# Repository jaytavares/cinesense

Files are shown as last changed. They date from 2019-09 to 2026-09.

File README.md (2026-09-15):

# Cinesense: an Audio Sensing Add-on for Bose Cinemate Speakers

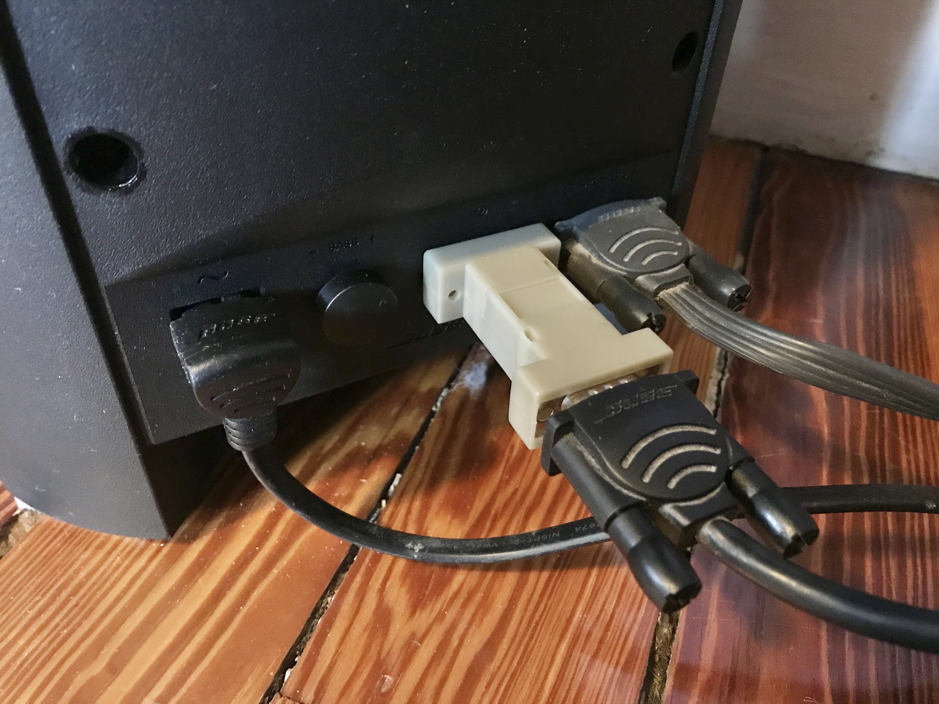
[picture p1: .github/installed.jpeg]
Assembled Board


## Overview

Do you have Bose Cinemate speakers? Do you wish they would just turn on automatically when you need them
and turn off when you're done. This project provides everything you need to do just that. Using it, you can create an
adapter that plugs into the interface module cable and adds audio sensing capability to your Bose Cinemate speakers.\*

\* This project only works with Bose Cinemate **Series II** speakers. Since the Cinemate Series I speakers don't have an optical audio input, the Cinesense will not work with them.

[Buy One!](#buy-one)

[Build It!](#the-parts-list)

## What People are Saying

> Amazing! Works perfectly. Didn’t expect it to auto shutoff after a couple of seconds when the source is powered off, so that’s a plus! Thanks again! _— Chris T._

> Just received it and installed it. What an awesome little gadget! Thanks for doing this for us and sending some joy our way. It may be a small thing. But pretty awesome! _— Jennifer S._

> Works like a charm! Thanks very much again. _— Miroslav V._

> Hey- just wanted to tell you the adapter works great! Thanks again! _— Graham L._

> Hey the adapter is installed and works great, thanks for making one for me, it's worth paying you for your ingenuity. I'm so much happier not having any remotes since I use google voice to do everything else other than volume changes. _— Enrique I._

> They work perfectly, thank you so much! _— David A._

> Received it today and it works as described. Thanks again! _— Jeremiah O._

> You’ve changed my life Jay!!!! Thank you!! _— Nathan R._

> The adapter works great! Thanks again Jay. _— Dmitrij P._

> Just got it in the mail, it's amazing!! Thank you so much! Timing was impeccable.. I literally was just looking at new speakers now I don't have to! You have no idea how happy this makes me haha _— Julie C._

> Dude, you’re a wizard! Love this thing. Who knew something so simple looking could be so helpful? Thanks again! _— Brian W._

### How It Works

When placed inline between the sub woofer module and the interface module, the Cinesense adapter repeatedly polls the
optical audio input for a signal. When a signal is sensed, the speakers are automatically turned on. The adapter will
continue to monitor the signal while the speakers are in use. Once the signal has stopped for ten seconds, the adapter
will turn the speakers off.

NOTE: The adapter only looks at the optical input and will not respond to audio signals on the analog inputs. This is a
potential future enhancement that can be made to the design. Also, the term "Audio Signal" here is referring to optical
audio "data" which is not the same as "sound". It's possible for the optical audio signal to be present _and_ silent
(e.g. music player is powered on but is paused).

Aside from the new found ability to automatically turn on and off in response to the audio signal, all aspects of the
speakers are the same. You can still use your remote to control the volume and mute the speakers. You can even use your
remote to turn the speakers off, though if there is an audio signal present, they'll just turn right back on again.

## Theory of Operation (for nerds)

Below I've included not just how the Cinesense works but everything I learned about these speakers in the course
of building this project. Hopefully it will be helpful to someone else interested in hacking these speakers.

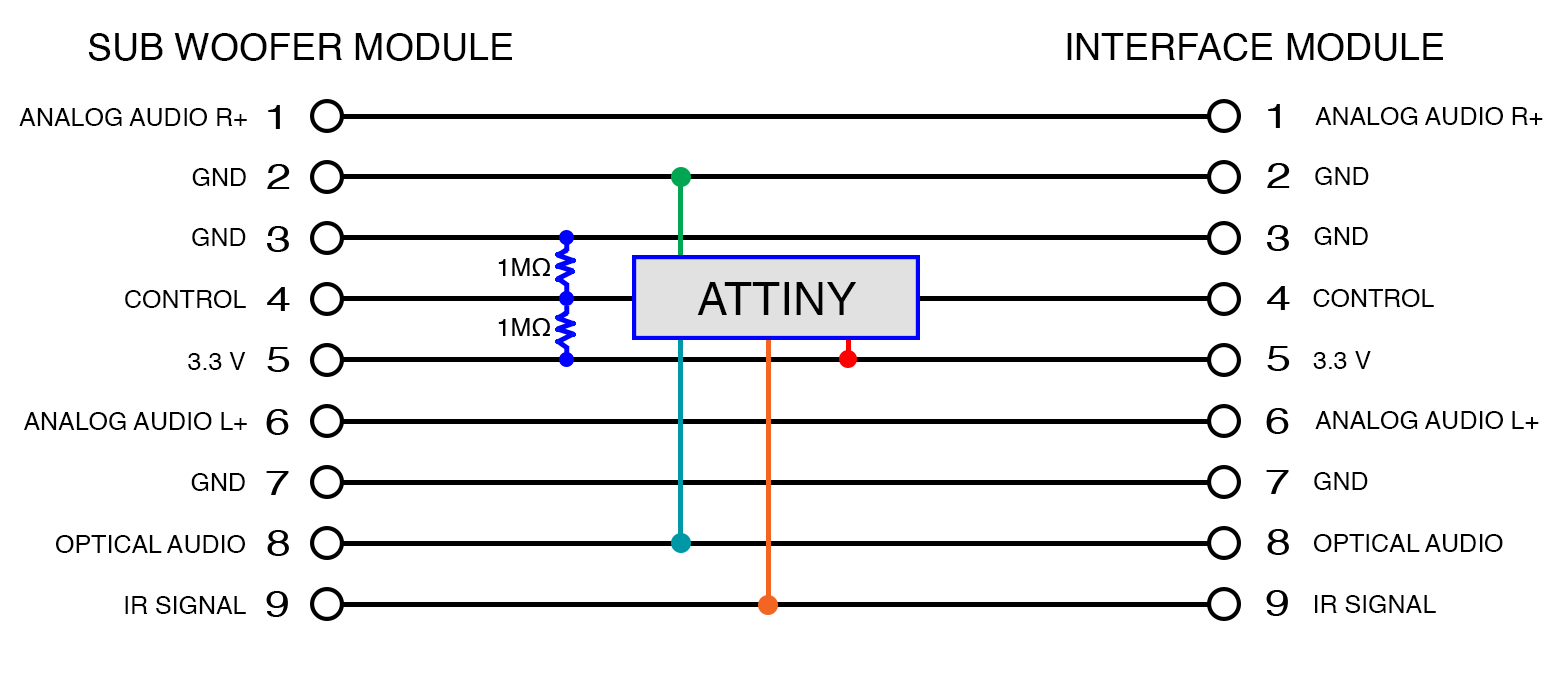
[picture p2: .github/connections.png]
Circuit overview


Some notes:

- Pin 4 - Interface module CONTROL LINE
  - Has three possible states
    - LOW - power off
    - HIGH - power on, LED on
    - FLOAT - power on, LED off
      - This is how the LED is able to flash when the speakers are muted and in response to remote button presses.
      - This allows us to turn on the optical input without also turning on the LED in the interface module. 👍
- Pin 8 - Optical audio
  - Digital audio data (Didn't seem to be at the same 3.3v logic level--it was lower.)
- Pin 9 - IR Line
  - Decoded IR data (NEC protocol) with no carrier frequency

As you can see in the diagram above, the micro-controller interrupts the control line in order to allow independent control of the interface
module. The control line input can be polled to determine the power state of the speakers, the resistors on the control
line input act as a voltage divider allowing the micro-controller to accurately detect the floating state. By floating
the control line output, the interface module can be turned on without lighting its LED or turning on the speakers. This
supplies power to the optical input and allows us to check for a signal.

In my experimentation, it didn't appear that I could turn on the speakers by simply bringing the control line high. So,
instead, when an audio signal is sensed, I inject the 'ON' infrared command directly into the IR Line. This simulates
pressing the on button on the remote and the speaker system powers on in turn. Since we are tapping into the IR data line
directly, we need only inject the command itself with no carrier frequency. These speakers use the NEC IR protocol.
Here are the commands that they support:

- 0x5D0532CD On/Off
- 0x5D05C03F Vol. Up
- 0x5D0540BF Vol. Down
- 0x5D05807F Mute

## Buy One

[Click here for the latest information on availability.](./BUY_ONE.md)

## The Parts List

You'll need a few parts:

### The PCB

- 1x [Printed circuit board](https://oshpark.com/shared_projects/PZXtdoM9)

### The Components

Fast order: Click for a shopping cart with all the needed components

[Digi-Key](https://www.digikey.com/short/znq4vb) | [Mouser](https://www.mouser.com/ProjectManager/ProjectDetail.aspx?AccessID=052330197b)

- 1x Dual sided hood
- 1x DB9 Male connector
- 1x DB9 Female connector
- 1x ATTINY85 microchip
- 2x 1㏁ resistors
- 1x 1µF capacitor
- 1x 2x3 header (_Optional_--only needed if you plan to program the chip on the board.)

## The Tools

You'll need soldering supplies to assemble the board and a way to program the microchip. I use the [Pocket AVR Programmer](https://www.sparkfun.com/products/9825) from SparkFun.

## The Circuit Board

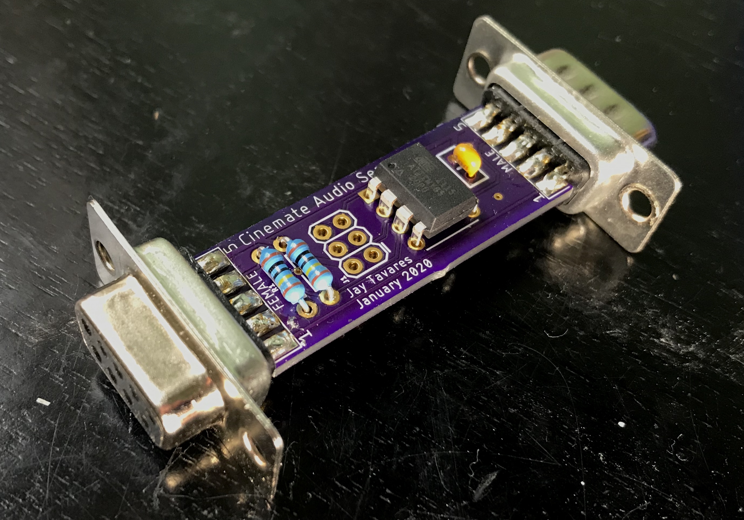
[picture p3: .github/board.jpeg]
Assembled circuit board


### Quick & Easy

For convenience, You can purchase the board on [OSHPark](https://oshpark.com/shared_projects/PZXtdoM9).

### Schematic and Board layout file

The board was originally designed in EAGLE CAD, but Autodesk has discontinued EAGLE and the files are now best viewed in Fusion. If you need to inspect or modify the design, you will find the original CAD files in the [board](./board) folder.

For convenience, viewable schematic files have been included in the [schematic](./schematic) folder for anyone who does not have access to Fusion.

### Assembly

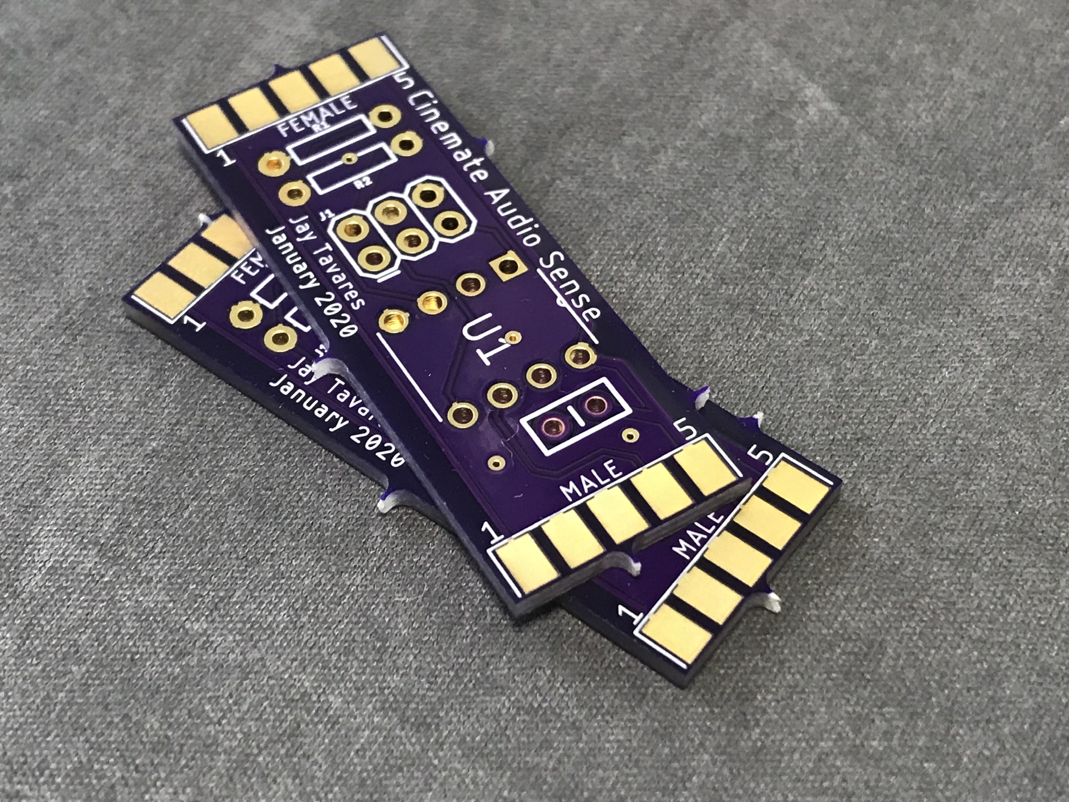
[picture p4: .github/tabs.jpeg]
Tabs on circuit boards


Before you start assembly, be sure to file off any tabs left on your boards as a result of panelization. If you skip this
step, you'll have trouble fitting the completed board into the housing. This is especially important for tabs along the
short edges where the DB9 connectors attach. After removing the tabs, I dry fit the connectors on the board and placed
everything in one half of the housing. I was then able to tack solder the connectors in place to ensure the final
assembly would fit in the housing.

## The Software

### Use Precompiled software (Easiest option)

1.  Download the most recent `firmware.hex` file from the [Releases](https://github.com/jaytavares/cinesense/releases) page.
2.  Connect your AVR Programmer to the chip. (I've included an ISP header on the board if you don't have a standalone programmer for ATTINY chips.)
3.  Use [avrdude](http://savannah.nongnu.org/projects/avrdude/) to program the ATTINY chip. Assuming you're using the "Pocket AVR Programer", run:

```
$ avrdude -c usbtiny -p t85 -U lfuse:w:0xe2:m -U hfuse:w:0xdf:m -U efuse:w:0xff:m -U flash:w:firmware.hex:i
```

### Build from the source (Most flexible option)

If you would like to customize your Cinesense, you'll have to build the software from the source. The software for this project is built using the fantastic [PlatformIO](https://platformio.org).

#### Programming the chip

1.  Connect your AVR Programmer to the chip. (I've included an ISP header on the board if you don't have a standalone programmer for ATTINY chips.)
2.  In the root directory of this project, run:

```
platformio run
```

This should compile the software, burn the correct fuses, and upload the software to the chip.

## Legal

This project is licensed under the MIT License. See [LICENSE.txt](LICENSE.txt) for more information. "Bose" and "Cinemate" are registered trademarks of Bose Corporation, Framingham, MA. This project is not endorsed by or affiliated with the Bose Corporation.

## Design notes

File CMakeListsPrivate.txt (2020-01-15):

# !!! WARNING !!! AUTO-GENERATED FILE, PLEASE DO NOT MODIFY IT AND USE
# https://docs.platformio.org/page/projectconf/section_env_build.html#build-flags
#
# If you need to override existing CMake configuration or add extra,
# please create `CMakeListsUser.txt` in the root of project.
# The `CMakeListsUser.txt` will not be overwritten by PlatformIO.

set(CMAKE_CONFIGURATION_TYPES "attiny85" CACHE STRING "" FORCE)

set(PLATFORMIO_CMD "/usr/local/bin/platformio")

SET(CMAKE_C_COMPILER "$ENV{HOME}/.platformio/packages/toolchain-atmelavr/bin/avr-gcc")
SET(CMAKE_CXX_COMPILER "$ENV{HOME}/.platformio/packages/toolchain-atmelavr/bin/avr-g++")
SET(CMAKE_CXX_FLAGS_DISTRIBUTION "-fno-exceptions -fno-threadsafe-statics -fpermissive -std=gnu++11 -Os -Wall -ffunction-sections -fdata-sections -flto -mmcu=attiny85")
SET(CMAKE_C_FLAGS_DISTRIBUTION "-std=gnu11 -fno-fat-lto-objects -Os -Wall -ffunction-sections -fdata-sections -flto -mmcu=attiny85")

SET(CMAKE_C_STANDARD 11)
set(CMAKE_CXX_STANDARD 11)

if (CMAKE_BUILD_TYPE MATCHES "attiny85")
    add_definitions(-D'PLATFORMIO=40100')
    add_definitions(-D'ARDUINO_AVR_ATTINYX5')
    add_definitions(-D'F_CPU=8000000L')
    add_definitions(-D'ARDUINO_ARCH_AVR')
    add_definitions(-D'ARDUINO=10808')
    add_definitions(-D'__AVR_ATtiny85__')

    include_directories("${CMAKE_CURRENT_LIST_DIR}/include")
    include_directories("${CMAKE_CURRENT_LIST_DIR}/src")
    include_directories("$ENV{HOME}/.platformio/packages/framework-arduino-avr-attiny/cores/tiny")
    include_directories("$ENV{HOME}/.platformio/packages/framework-arduino-avr-attiny/variants/tinyX5")
    include_directories("$ENV{HOME}/.platformio/packages/framework-arduino-avr-attiny/libraries/ATTinyCore/src")
    include_directories("$ENV{HOME}/.platformio/packages/framework-arduino-avr-attiny/libraries/EEPROM")
    include_directories("$ENV{HOME}/.platformio/packages/framework-arduino-avr-attiny/libraries/SPI")
    include_directories("$ENV{HOME}/.platformio/packages/framework-arduino-avr-attiny/libraries/Servo/src")
    include_directories("$ENV{HOME}/.platformio/packages/framework-arduino-avr-attiny/libraries/Servo_ATTinyCore/src")
    include_directories("$ENV{HOME}/.platformio/packages/framework-arduino-avr-attiny/libraries/SoftwareSerial")
    include_directories("$ENV{HOME}/.platformio/packages/framework-arduino-avr-attiny/libraries/Wire/src")
    include_directories("$ENV{HOME}/.platformio/packages/framework-arduino-avr-attiny/libraries/tinyNeoPixel")
    include_directories("$ENV{HOME}/.platformio/packages/framework-arduino-avr-attiny/libraries/tinyNeoPixel_Static")
    include_directories("$ENV{HOME}/.platformio/packages/toolchain-atmelavr/avr/include")
    include_directories("$ENV{HOME}/.platformio/packages/toolchain-atmelavr/lib/gcc/avr/5.4.0/include")
    include_directories("$ENV{HOME}/.platformio/packages/toolchain-atmelavr/lib/gcc/avr/5.4.0/include-fixed")
    include_directories("$ENV{HOME}/.platformio/packages/tool-unity")
endif()

FILE(GLOB_RECURSE SRC_LIST "${CMAKE_CURRENT_LIST_DIR}/src/*.*" "${CMAKE_CURRENT_LIST_DIR}/lib/*.*" "${CMAKE_CURRENT_LIST_DIR}/.pio/libdeps/attiny85/*.*")

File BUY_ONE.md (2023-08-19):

# Buy a Cinesense Adapter

While I am no longer building Cinesense adapters, another user has stepped up to the plate and is offering them for sale.

[Order one here!](https://www.paypal.com/instantcommerce/checkout/G5U4UX4U4Z9H8)

For all assistance with purchases contact him here:

- Reddit: [u/Axodude](https://www.reddit.com/user/Axodude/)
- GitHub: [johnrstillwell](https://github.com/johnrstillwell)

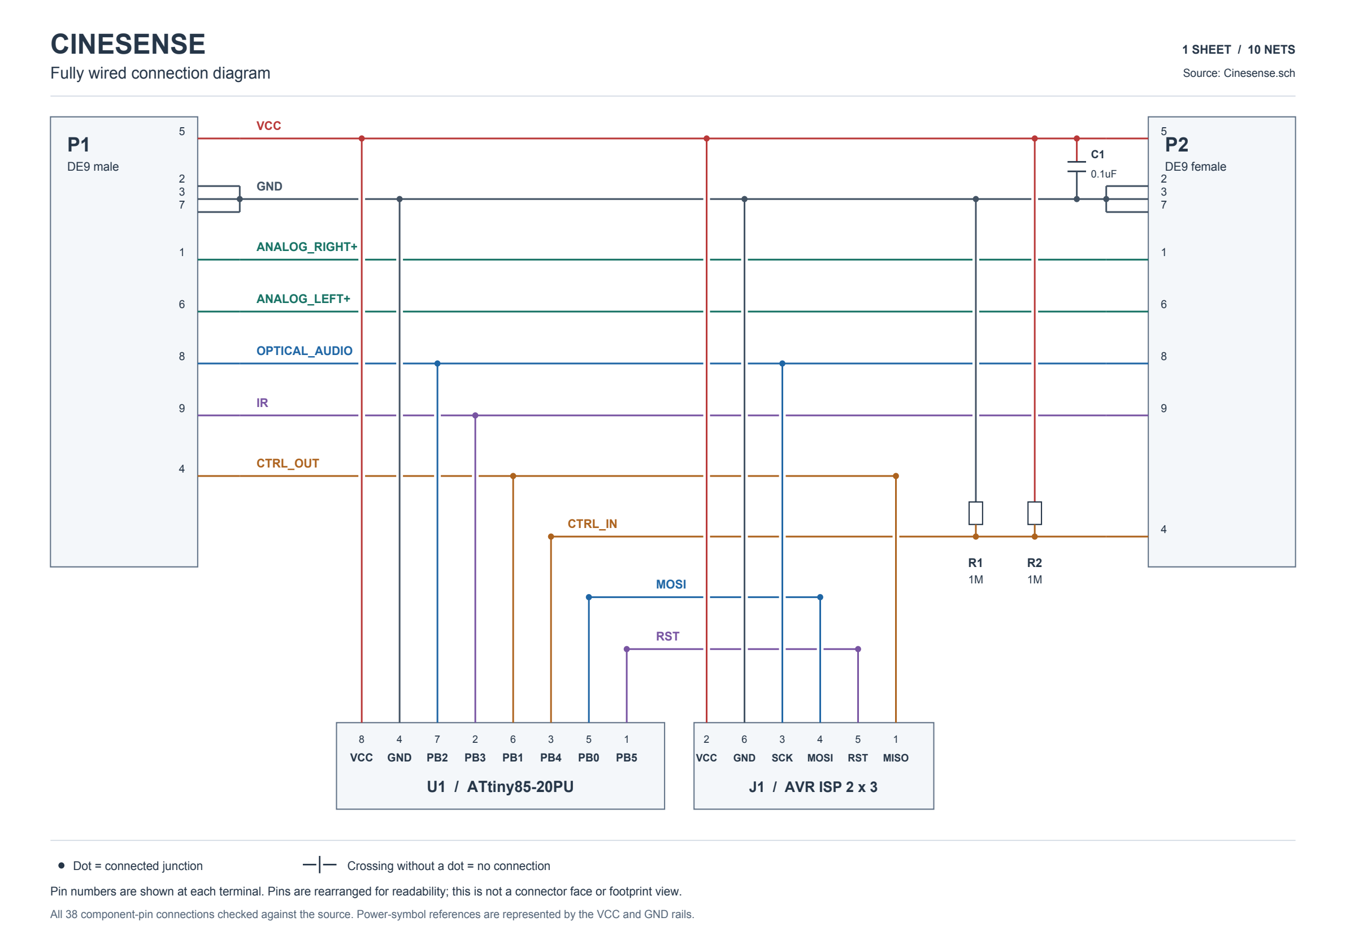
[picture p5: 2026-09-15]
schematic/Cinesense-schematic.png

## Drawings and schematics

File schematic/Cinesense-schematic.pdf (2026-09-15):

# CINESENSE

## Fully wired connection diagram

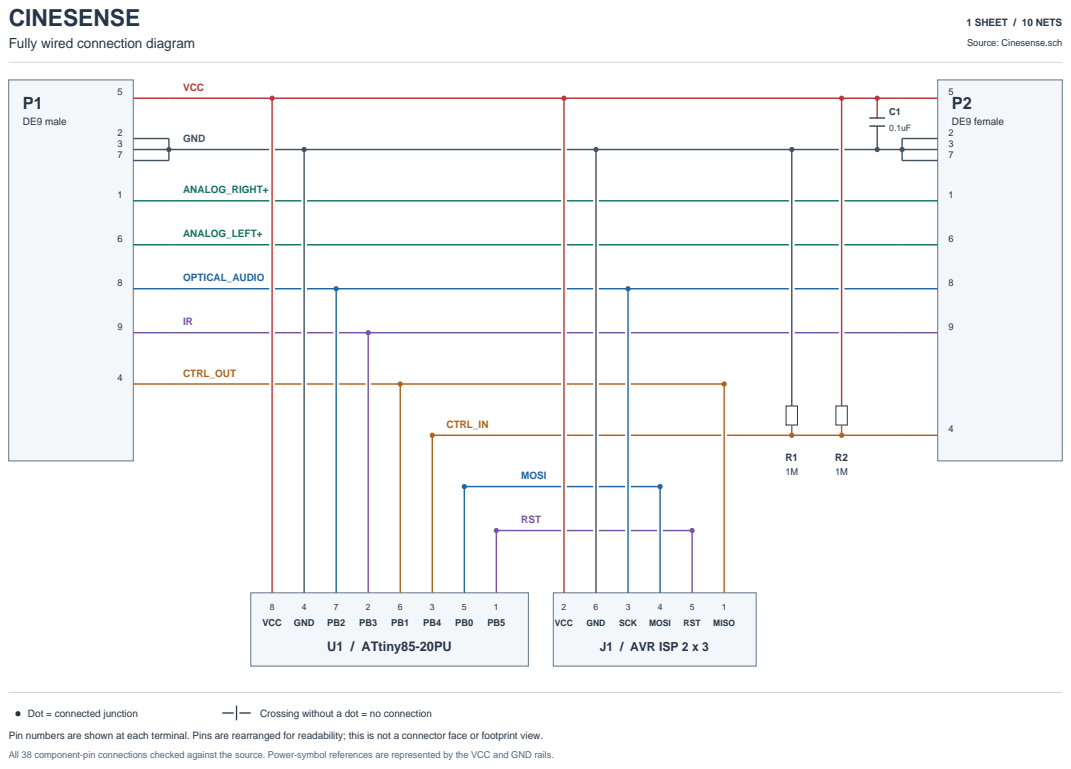
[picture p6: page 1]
DE9 male; DE9 female; VCC; GND; ANALOG_RIGHT+; ANALOG_LEFT+; OPTICAL_AUDIO; CTRL_OUT; CTRL_IN; MOSI; RST; 8 VCC; 4 GND; U1 / ATtiny85-20PU; SCK; MISO; J1 / AVR ISP 2 x 3; Dot = connected junction; Crossing without a dot = no connection

1 SHEET / 10 NETS
Source: Cinesense.sch

Pin numbers are shown at each terminal. Pins are rearranged for readability; this is not a connector face or footprint view.
All 38 component-pin connections checked against the source. Power-symbol references are represented by the VCC and GND rails.

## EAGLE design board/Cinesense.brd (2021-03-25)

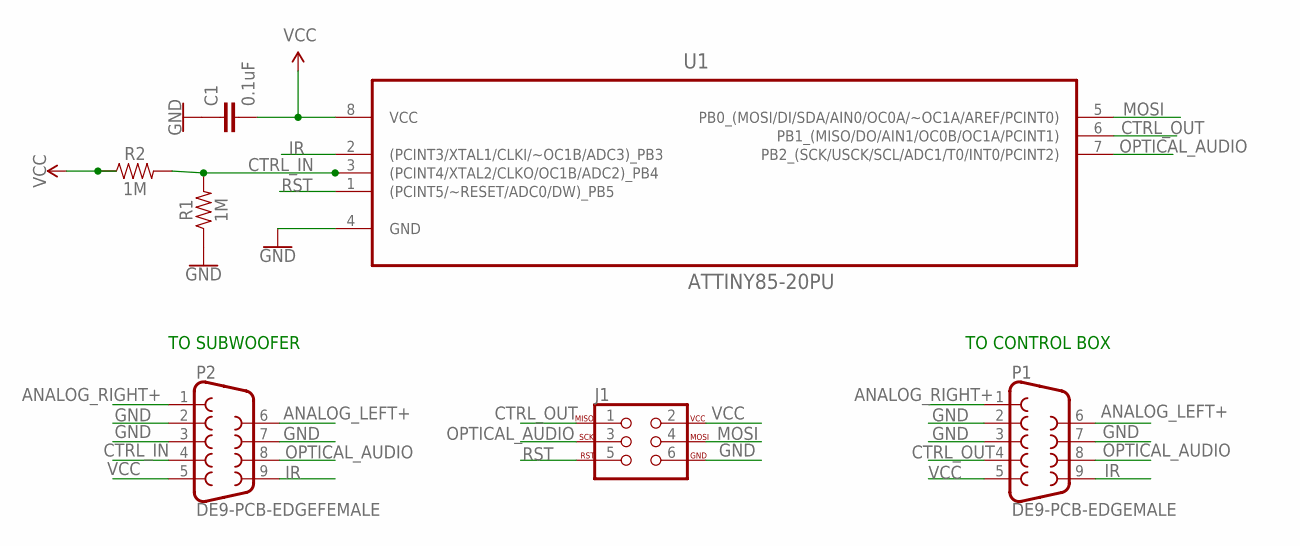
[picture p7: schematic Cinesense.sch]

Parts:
C1: 0.1uF; CAP-PTH-SMALL-KIT
J1: AVR_SPI_PROG_3X2PTH; 2X3
P1: DE9-PCB-EDGEMALE; DE9-EDGE-M
P2: DE9-PCB-EDGEFEMALE; DE9-EDGE-F
R1, R2: 1M; AXIAL-0.3
U1: ATTINY85-20PU; DIP254P762X533-8

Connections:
ANALOG_LEFT+: P1.6, P2.6
ANALOG_RIGHT+: P1.1, P2.1
CTRL_IN: P2.4, R1.P$2 (2), R2.P$2 (2), U1.3 ((PCINT4/XTAL2/CLKO/OC1B/ADC2)_PB4)
CTRL_OUT: J1.1, P1.4, U1.6 (PB1_(MISO/DO/AIN1/OC0B/OC1A/PCINT1))
GND: C1.1, J1.6, P1.2, P1.3, P1.7, P2.2, P2.3, P2.7, R1.P$1 (1), U1.4 (GND)
IR: P1.9, P2.9, U1.2 ((PCINT3/XTAL1/CLKI/~OC1B/ADC3)_PB3)
MOSI: J1.4, U1.5 (PB0_(MOSI/DI/SDA/AIN0/OC0A/~OC1A/AREF/P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)
OPTICAL_AUDIO: J1.3, P1.8, P2.8, U1.7 (PB2_(SCK/USCK/SCL/ADC1/T0/INT0/PCINT2))
RST: J1.5, U1.1 ((PCINT5/~RESET/ADC0/DW)_PB5)
VCC: C1.2, J1.2, P1.5, P2.5, R2.P$1 (1), U1.8 (VCC)

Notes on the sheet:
TO SUBWOOFER
TO CONTROL BOX

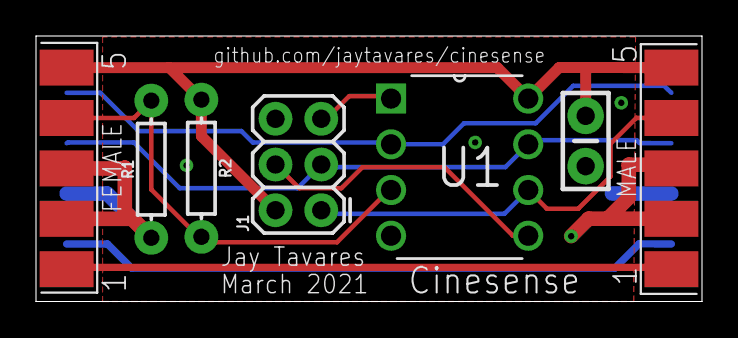
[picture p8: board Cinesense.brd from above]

Board: 2 copper layers, 37.0 x 14.8 mm, 7 parts (0 on the bottom side), 10 nets.

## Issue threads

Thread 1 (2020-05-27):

Speakers unresponsive after power failure

jaytavares, 2020-05-27:
Following loss of power, speakers will no longer power on.

To reproduce, unplug speaker power cable with Cinesense installed and working. Upon restoring power, LED on interface module will flash for 10 seconds as if muted. After that, the speakers will remain unresponsive to audio and IR remote control signals.

I'm still investigating the root cause of this issue. With the Cinesense installed, a power failure seems to trigger some kind of lock out mode in the speakers. While locked out, the speakers no longer respond to IR commands. Since this is how the Cinesense controls the speakers, this means that the speakers cannot be powered on automatically or via the remote control.

**To resolve the issue:**
1. Unplug the speaker's power cord from the wall.
1. Remove the Cinesense adapter from your speakers.
1. Reattach interface module cable directly to subwoofer, leaving Cinesense disconnected.
1. Plug power cord back into the wall.
1. Wait for the LED on the interface module to stop flashing.
1. Reinstall the Cinesense adapter while keeping power cord plugged in.

jaytavares, 2020-05-27:
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

jaytavares, 2022-04-13:
I figured out the cause of this issue today and fixed it. The culprit is the pull up resistor on the CONTROL_IN line. In my troubleshooting, I discovered that the presence of positive voltage on that line during power up would result in the behavior described above. The behavior was not exhibited when the line was held low or left floating. To fix the issue, I added an initialization step to the setup routing that holds the line low for four seconds. That seems to have fixed it.

Closed 2022-04-12.

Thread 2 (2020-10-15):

Preassembled devices

maxkfranz, 2020-10-15:
Do you sell preassembled devices?  It's great that you've open-sourced the project, but I'd rather buy than DIY.

In any case, thanks for your project!  I've wanted to sort out this issue on my speakers for a while now.

My email address is maxkfranz@gmail.com

jarevalo31, 2020-10-19:
Hi Jay.

I'm also interested in a preassembled device. Can we connect to see if I can get one? Thanks! My email is jorge.arevalo@mac.com

superwdy, 2020-10-19:
+1. @jaytavares DIY with soldering tools might not be a choice for lots of regular Bose consumers. It's be really helpful if you could sell it. I'm not sure about the market size but if you are interested in finding a manufacturer to bulk produce I could help with connecting you with some Chinese manufacturer.

jaytavares, 2020-10-19:
Hey there. I've made some for people who are in your same position. I don't think there's enough demand to justify large scale manufacture. So, I've just been assembling small runs myself.

maxkfranz, 2020-10-19:
@jaytavares, it might be useful to add contact information to the readme for people who’d like a preassembled device. Also, some people who self assemble may be interested in donating through GitHub sponsors.

My main motivation was to support the author of the project, though I’d also rather not have a soldering project. It’s great to see open source projects like this one. Thanks, Jay.

jaytavares, 2020-10-22:
> @jaytavares, it might be useful to add contact information to the readme for people who’d like a preassembled device. Also, some people who self assemble may be interested in donating through GitHub sponsors.
>
> My main motivation was to support the author of the project, though I’d also rather not have a soldering project. It’s great to see open source projects like this one. Thanks, Jay.

Good idea @maxkfranz, I’ll add a note with some contact information to the readme.

jaytavares, 2020-10-22:
@maxkfranz Oh and I also really appreciate your support!

jipiboily, 2020-12-20:
Hello @jaytavares!

Would love to know if you are willing to build and sell one more?

if so, how can I reach you for the details? You can also email me at j@jipi.ca

Thanks!

jaytavares, 2021-01-17:
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

I just added a direct purchase link to the [readme](https://github.com/jaytavares/cinesense). Hopefully this helps!

Closed 2020-10-19.

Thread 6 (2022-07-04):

v1.1.0 and v1.1.1 firmwares broken by bad CLOCK_SOURCE default in atmelavr 3.4.0

msparks, 2022-07-04:
**TL;DR**: [platformio/platform-atmelavr](https://github.com/platformio/platform-atmelavr) 3.4.0 contains a bug that causes the ATtiny85 to run at 4 MHz instead of 8 MHz, which is enough to completely break Cinesense. The **firmware in the v1.1.1 release is DOA** for me – no auto-off/on behavior at all – but the firmware binary in the v1.0.0 release *does* work. The v1.1.0 and v1.1.1 releases were built (by GitHub Actions) [using the broken atmelavr 3.4.0](https://github.com/jaytavares/cinesense/runs/6116544230?check_suite_focus=true). atmelavr 4.0.0 contains a fix for the bug.

This issue affects builds of Cinesense that used [platformio/platform-atmelavr](https://github.com/platformio/platform-atmelavr) 3.4.0 only. The root cause was [fixed upstream in 4.0.0](https://github.com/platformio/platform-atmelavr/releases/tag/v4.0.0). What follows below is a detailed version of https://github.com/platformio/platform-atmelavr/issues/264 as it applies to Cinesense. (I wrote most of the following before finding that issue. I'm leaving all of the details here in case someone falls into the same bad-package trap that I did.)

### Background

I ran into this problem when I tried flashing the v1.1.1 firmware to my Dec 2021 Cinesense, hoping to pull in the fix for #1. My journey was as follows:

1. Flashed `firmware.hex` from v1.1.1 using `avrdude`. **Result**: Cinesense functionality didn't seem to work at all. Speakers (and interface module LED) would stay on without a signal, and stay off with a signal.
2. Flashed `firmware.hex` from v1.0.0. **Result**: Cinesense worked as expected.
3. Cloned the repo, and ran `pio run` to compile and flash. **Result**: Same as v1.1.1 official release, non-functional.
4. `git checkout v1.0.0`, then `pio run` to run the v1.0.0 code. **Result**: Still broken (!).

After a few other dead ends, I read through the [Theory of Operation](https://github.com/jaytavares/cinesense#theory-of-operation-for-nerds) and then the code. To see if I could get _anything_ working from source, I added this to the top of `loop()` to make the interface module's LED blink:

```c++
pinMode(CONTROL_OUT, OUTPUT);
digitalWrite(CONTROL_OUT, HIGH);
delay(5000);
pinMode(CONTROL_OUT, OUTPUT);
digitalWrite(CONTROL_OUT, LOW);
delay(500);
return;
```

Surprisingly, the LED stayed on for *10* seconds, not *5* seconds as written. That led to discovering https://community.platformio.org/t/board-build-f-cpu-parameter-has-no-effect-on-attiny85/25485, which precisely describes the problem.

### Problem statement

Cinesense sets the ATtiny85 low fuse bits to [`0xE2`](http://eleccelerator.com/fusecalc/fusecalc.php?chip=attiny85&LOW=E2&HIGH=DF&EXTENDED=FF&LOCKBIT=FF) to use the internal oscillator at 8MHz. However, the value of the [`CLOCK_SOURCE` define](https://github.com/SpenceKonde/ATTinyCore#determining-clock-speed-and-source-from-within-the-sketch) can affect the clock prescalar, and in [atmelavr 3.4.0](https://github.com/platformio/platform-atmelavr/releases/tag/v3.4.0), the default for `CLOCK_SOURCE` for ATtiny85 changed [from `0` to `6`](https://github.com/platformio/platform-atmelavr/commit/012de336af56472e65e2db2e6c2d95d9a137803d), where:

> - 0 - Internal 8MHz oscillator, not prescaled, or prescaled to 1 MHz (ie, fully set by fuses)
> - 6 - Internal PLL (x5 and x61 only)

When `CLOCK_SOURCE` is `6`, the atmelavr code believes the 16MHz PLL is being used, and `F_CPU` is set to 8 MHz, so [it sets a clock division of 2 to match 8 MHz](https://github.com/SpenceKonde/ATTinyCore/blob/master/avr/cores/tiny/wiring.c#L1041-L1050) from a supposed 16 MHz clock source. But since the fuses select the internal RC oscillator running at 8 MHz, the division by 2 causes the ATtiny to run at 4 MHz, thus `delay()`s run for twice as long as they should.

### Evidence

Here's what I see when compile Cinesense at HEAD, using PlatformIO with the Atmel AVR 3.4.0 platform:

```
% pio run -t clean
% pio debug -v
Processing attiny85 (platform: atmelavr; board: attiny85; framework: arduino; board_fuses.lfuse: 0xE2; board_fuses.hfuse: 0xDF; board_fuses.efuse: 0xFF; targets: fuses, upload)
------------------------------------------------------------------------------------------------------------------------------------------------------------------------
CONFIGURATION: https://docs.platformio.org/page/boards/atmelavr/attiny85.html
PLATFORM: Atmel AVR (3.4.0) > Generic ATtiny85
HARDWARE: ATTINY85 8MHz, 512B RAM, 8KB Flash
DEBUG: Current (simavr) On-board (simavr)
PACKAGES:
 - framework-arduino-avr-attiny @ 1.5.2
 - toolchain-atmelavr @ 1.70300.191015 (7.3.0)
LDF: Library Dependency Finder -> https://bit.ly/configure-pio-ldf
LDF Modes: Finder ~ chain, Compatibility ~ soft
Found 9 compatible libraries
Scanning dependencies...
No dependencies
Building in debug mode
avr-g++ -o .pio/build/attiny85/src/AudioSense.cpp.o -c -fno-exceptions -fno-threadsafe-statics -fpermissive -std=gnu++11 -Wall -ffunction-sections -fdata-sections -flto -mmcu=attiny85 -Og -g2 -ggdb2 -DPLATFORMIO=60002 -DARDUINO_AVR_ATTINYX5 -DNEOPIXELPORT=PORTB -DCLOCK_SOURCE=6 -DF_CPU=8000000L -DARDUINO_ARCH_AVR -DARDUINO=10808 -D__PLATFORMIO_BUILD_DEBUG__ -Iinclude -Isrc -I/Users/ms/.platformio/packages/framework-arduino-avr-attiny/cores/tiny -I/Users/ms/.platformio/packages/framework-arduino-avr-attiny/variants/tinyX5 src/AudioSense.cpp
...
```

Note:
- `board_fuses.lfuse: 0xE2`
- `PLATFORM: Atmel AVR (3.4.0) > Generic ATtiny85`
- `-DCLOCK_SOURCE=6 -DF_CPU=8000000L`

### Solution

**Update `atmelavr` to 4.0.0** to restore the behavior prior to 3.4.0. 4.0.0 reverts the `CLOCK_SOURCE` default change from 3.4.0 (https://github.com/platformio/platform-atmelavr/issues/264).

From within the Cinesense repo:

```
% pio pkg update
Resolving attiny85 environment packages...
Platform Manager: Updating atmelavr @ 3.4.0
Platform Manager: Removing atmelavr @ 3.4.0
Platform Manager: atmelavr@3.4.0 has been removed!
Platform Manager: Installing platformio/atmelavr @ 4.0.0
Downloading  [####################################]  100%
Unpacking  [####################################]  100%
Platform Manager: atmelavr@4.0.0 has been installed!
```

(On 3.4.0, the workaround is to add [`build_unflags`](https://docs.platformio.org/en/stable/projectconf/section_env_build.html#build-unflags) to the `env:attiny85` section of `platformio.ini`:

```
build_unflags = -DCLOCK_SOURCE=6
```

This is a temporary workaround though; the stable interface is `build.clock_source`, introduced in 4.0.0.)

After updating:

```
% pio debug -v
Processing attiny85 (platform: atmelavr; board: attiny85; framework: arduino; board_fuses.lfuse: 0xE2; board_fuses.hfuse: 0xDF; board_fuses.efuse: 0xFF; targets: fuses, upload)
...
PLATFORM: Atmel AVR (4.0.0) > Generic ATtiny85
...
avr-g++ -o [...] -DCLOCK_SOURCE=0 [...] src/AudioSense.cpp
...
```

With `CLOCK_SOURCE` fixed, the blink example above had correct timing. I then built and flashed the code at HEAD and that worked as well. (And now I finally have a fix for #1!)

### Conclusion

The `atmelavr` platform at version 3.4.0 produces firmwares at that run Cinesense at 4 MHz. Version 4.0.0 (or a version older than 3.4.0) is required to produce a firmware that runs at the correct frequency (8 MHz).

The `firmware.hex` files in Cinesense v1.1.0 and v1.1.1 were built in 2022-04 by GitHub Actions, and the current version at that time was atmelavr 3.4.0. The [Action logs](https://github.com/jaytavares/cinesense/runs/6116544230?check_suite_focus=true) for the `Run PlatformIO` clearly show the use of the bad version:

```
Run pio ci --board=attiny85 --lib=include --project-option=platformio.ini --keep-build-dir --build-dir=build src
...
Platform Manager: Installing atmelavr
Downloading...
Unpacking...
Platform Manager: atmelavr @ 3.4.0 has been installed!
```

atmelavr 4.0.0, which contains the fix, wasn't released until [2022-05-31](https://github.com/platformio/platform-atmelavr/releases/tag/v4.0.0). Thus, the published firmwares of Cinesense v1.1.0 and v1.1.1 are nonfunctional.

No changes are required to the Cinesense code. And presumably by now the default version of atmelavr 4.0.0, so the next triggered release action should produce a working firmware.

jaytavares, 2022-07-06:
Thanks for the thorough troubleshooting @msparks. I'm sorry about those broken firmware releases. I've deleted them. To fix going forward I've updated the CI script to peg platformio at the latest stable version (6.1.0). That should prevent future upstream problems from creeping in to our firmware. Would you mind testing the latest v1.1.2 firmware to ensure the problem has been fixed?

Thanks again for all your sleuth work. 🥇

msparks, 2022-07-07:
> Would you mind testing the [latest v1.1.2 firmware](https://github.com/jaytavares/cinesense/releases/tag/v1.1.2) to ensure the problem has been fixed?

I just flashed the v1.1.2 firmware and can confirm it behaves as expected! 🎉

The [Actions build of v1.1.2](https://github.com/jaytavares/cinesense/runs/7221259865?check_suite_focus=true) also clearly shows the installation of atmelavr 4.0.0, so the latest release with the fix is being picked up correctly.

> To fix going forward I've updated the CI script to peg platformio at the current stable version (6.1.0).

Note that this pin won't apply to the `atmelavr` platform, only to PlatformIO itself. PlatformIO has its own package manager; during builds, it'll fetch the packages necessary to build for the platforms and frameworks specified in the `platformio.ini` file in the project. To guarantee stability, I think you'd also have to pin atmelavr to a specific version, e.g.,

```ini
[env:attiny85]
platform = atmelavr@4.0.0
...
```

Where `@4.0.0` means *exactly* 4.0.0. It's possible to use something like `@^4.0.0`, which means any `4.x.x` (backwards-compatible) version is acceptable, but of course that wouldn't prevent bugs from being introduced in a `4.x.x` release. (Ref: [Version Requirements](https://docs.platformio.org/en/latest/core/userguide/pkg/cmd_install.html#version-requirements))

In practice, this kind of showstopper bug should be rare (hopefully), and without a forcing function to revisit and update the pinned versions, it's possible that pinning creates more problems than it solves in the long run. So, a reasonable compromise might be to just avoid the known-bad package:

```ini
[env:attiny85]
platform = atmelavr@!=3.4.0
...
```

All that said, thanks for fixing the releases and for creating Cinesense. This was a fun learning experience. :)

jaytavares, 2022-07-08:
Ah, gotcha. I've pinned it to v4. I'd rather shoot for deterministic builds since this firmware won't be seeing a ton of new development/features. The only real thing left is analog audio sensing which I'm working on currently.

Thanks again for your work on this.

Temtaime, 2025-01-04:
So how one should select 16MHz for attiny85 ?
I still get error `framework-arduino-avr-attiny\cores\tiny\wiring.c:1095:8: error: #error "Frequency requested from internal oscillator that cannot be generated by prescaling"` with the latest version, but related bugreport is closed

Closed 2022-07-06.

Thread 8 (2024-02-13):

doesn't work, on Cinemate Serie II, Please someone help me.

FullReg, 2024-02-13:
I do all the process, i order PCB, grab all parts as it was listed, i did tree of same, with version 1.13. But when my friend test it , they tell me all tree circuits as i made as the same issue, power come on and after they can not change the volume, and when they close the TV set the Bose doesn't close. He as Cinemate Serie II.
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

I try to compile the version with Arduino IDE 1.8.19, and i am not an expert but i didn't work, with a lot of error of compilation. i used the hex file with
AVRDUDESS-master. I was upload to the ATTyni85 and the verify tell me it's ok.
Now I'm completely lost
Please someone help me.

werty1st, 2024-03-19:
i want to try it. but i don't have an attiny. i will try it with an esp32-c3.

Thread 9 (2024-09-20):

Intermittent Mute

jrmiii, 2024-09-20:
I recently built one and love it. The only issue I have is that occasionally it will be stuck on mute and the only way to fix it is a power cycle.

When it happens,at random the Cinemate flashes the mute pattern even though mute has not been pressed. While in this state, pressing the mute button turns the light to solid for about a second or less, then goes back to mute pattern. No audio  can be heard.  Power cycle fixes it for a while but I can't see a pattern to what causes it.

Any ideas? Thanks!

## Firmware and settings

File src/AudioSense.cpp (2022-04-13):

#include <Arduino.h>
#include "Pins.h"
#include "IRDirect.h"

// Uncomment to enable serial debugging
//#define DEBUG

// Define settings
// Automatic speaker power trigger times
#define ON_TRIGGER_TIME 300  // milliseconds; Signal must be present for this long before speakers are powered on
#define OFF_TRIGGER_TIME 1000 * 10 // seconds; Signal must be absent for this long before speakers are powered off

// Audio signal must be LOW for this amount of time to be considered absent
#define SIGNAL_THRESHOLD 100  // milliseconds

// IR power on/off command
#define POWER_COMMAND 0x5D0532CD

// Helper functions >>
bool powerOn() {
    return analogRead(CONTROL_IN) > 50;
}

bool ledOn() {
    return analogRead(CONTROL_IN) > 700;
}

bool checkSignal() {
    bool SIG_SENSED = false;

    // Find out if speaker is off
    bool POWER_OFF = !powerOn();

    // If speaker is off, float the CONTROL_OUT line.
    // This will turn on the optical input but won't turn on the power LED.
    if (POWER_OFF)
        pinMode(CONTROL_OUT, INPUT);

    // Check for audio signal
    unsigned long startTime = millis();
    while (millis() - startTime < SIGNAL_THRESHOLD) {
        if (analogRead(AUDIO_SENSE_PIN) > 100) {
            // A signal was sensed for longer than the threshold setting
            SIG_SENSED = true;
        }
    }

    if (POWER_OFF){
        // Reconnect CONTROL LINE
        pinMode(CONTROL_OUT, OUTPUT);
    }

    return SIG_SENSED;
}

// Initial power up
void setup() {
#ifdef DEBUG
    Serial.begin(115200);
#endif
    pinMode(AUDIO_SENSE_PIN, INPUT);
    pinMode(CONTROL_OUT, OUTPUT);
    pinMode(IR_LINE, INPUT);
    pinMode(CONTROL_IN, OUTPUT);

    // Start-Up routine >>>

    // CONTROL_IN must be held low for at least 4 seconds on power up in order to avoid locking out the speakers (see https://github.com/jaytavares/cinesense/issues/1)
    digitalWrite(CONTROL_IN, LOW);
    delay(4000);
    pinMode(CONTROL_IN, INPUT);

    // Send power command for faster initial start up.
    sendNEC(POWER_COMMAND);
}

bool lastPowerState = false;
bool lastSignalState = false;

unsigned long stateStartTime = 0;

// Main loop
void loop() {

    if (ledOn()) {
        pinMode(CONTROL_OUT, OUTPUT);
        digitalWrite(CONTROL_OUT, HIGH);
    } else
        pinMode(CONTROL_OUT, INPUT);

    bool poweredOn = powerOn();
    if (!poweredOn){
        pinMode(CONTROL_OUT, OUTPUT);
        digitalWrite(CONTROL_OUT, LOW);
    }

    if (lastPowerState != poweredOn) {
#ifdef DEBUG
        Serial.print("Power: ");
        Serial.println(poweredOn ? "ON" : "OFF");
#endif
        stateStartTime = millis();
    }
    lastPowerState = poweredOn;

    bool signalPresent = checkSignal();
    if (lastSignalState != signalPresent) {
#ifdef DEBUG
        Serial.print("Audio signal: ");
        Serial.println(signalPresent);
#endif
        stateStartTime = millis();
    }
    lastSignalState = signalPresent;

    unsigned long stateTimer = millis() - stateStartTime;

    // Auto power on
    if (signalPresent && !poweredOn){
#ifdef DEBUG
        Serial.print("ON Delay: ");
        Serial.println(stateTimer);
#endif
        if (stateTimer >= ON_TRIGGER_TIME){
            sendNEC(POWER_COMMAND);
        }
    }

    // Auto power off
    if (!signalPresent && poweredOn){
#ifdef DEBUG
        Serial.print("OFF Delay: ");
        Serial.println(stateTimer);
#endif
        if (stateTimer >= OFF_TRIGGER_TIME){
            sendNEC(POWER_COMMAND);
        }
    }
}

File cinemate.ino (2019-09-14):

#include <Arduino.h>
#include "User_Setup.h"

///*
// * IRremote: IRrecvDemo - demonstrates receiving IR codes with IRrecv
// * An IR detector/demodulator must be connected to the input RECV_PIN.
// * Version 0.1 July, 2009
// * Copyright 2009 Ken Shirriff
// * http://arcfn.com
// */
//
//#include <IRremote.h>
//
//int RECV_PIN = 11;
//
//IRrecv irrecv(RECV_PIN);
//
//decode_results results;
//
//void setup()
//{
//  Serial.begin(9600);
//  // In case the interrupt driver crashes on setup, give a clue
//  // to the user what's going on.
//  Serial.println("Enabling IRin");
//  irrecv.enableIRIn(); // Start the receiver
//  Serial.println("Enabled IRin");
//}
//
//void loop() {
//  if (irrecv.decode(&results)) {
//    Serial.println(results.value, HEX);
//    irrecv.resume(); // Receive the next value
//  }
//  delay(100);
//}
//
///*
// * IRremote: IRsendDemo - demonstrates sending IR codes with IRsend
// * An IR LED must be connected to Arduino PWM pin 3.
// * Version 0.1 July, 2009
// * Copyright 2009 Ken Shirriff
// * http://arcfn.com
// */
//
//
//#include <IRremote.h>
//
//IRsend irsend;


// pulse parameters in usec
#define NEC_HDR_MARK  9000
#define NEC_HDR_SPACE 4500
#define NEC_BIT_MARK  560
#define NEC_ONE_SPACE 1600
#define NEC_ZERO_SPACE  560
#define NEC_RPT_SPACE 2250

#define TOPBIT 0x80000000

const int OutputPin = 13;

void setup()
{
    pinMode(OutputPin, OUTPUT);
    digitalWrite(OutputPin, HIGH);
}

void mark(int time) {
    digitalWrite(OutputPin, LOW);
    delayMicroseconds(time);
}

void space(int time) {
    digitalWrite(OutputPin, HIGH);
    delayMicroseconds(time);
}

void sendNEC(unsigned long data) {
    mark(NEC_HDR_MARK);
    space(NEC_HDR_SPACE);

    for (int i = 0; i < 32; i++) {
        if (data & TOPBIT) {
            mark(NEC_BIT_MARK);
            space(NEC_ONE_SPACE);
        }
        else {
            mark(NEC_BIT_MARK);
            space(NEC_ZERO_SPACE);
        }
        data <<= (uint8_t) 1;
    }
    mark(NEC_BIT_MARK);
    space(0);
}

void loop() {
    sendNEC(0x5D0532CD);
    delay(5000);
}

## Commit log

2020-01-11 Add note about hi-Z control_in pin, speed up loop
2020-01-11 First working version with automatic power on
2020-01-11 Add automatic power off
2020-01-11 Disable automatic power off
2020-01-16 Add audio sensing and auto power back in
2020-02-06 Add Eagle files & readme
    [Cinemate.brd, Cinemate.sch]
2020-03-23 Update resistor link in readme
2020-04-29 Change link to capacitor
2020-05-14 Add link to PCB in parts list
2020-06-02 Remove note about resistor--they fit
2020-06-06 Update product links
    Fix incorrect female connector, change all links to Mouser for since some
    are out of stock at DigiKey.
2020-10-13 Add BOM links for Digi-Key and Mouser
2021-03-25 Update board & ignore .vscode
    Reduce length of board by 1 mm to allow for a better fit in the enclosure
    [Cinemate.brd]
2021-03-25 Rename Eagle files
    [Cinesense.brd, Cinesense.sch]
2021-03-25 Add github link to board silkscreen
    [Cinesense.brd]
2022-04-12 Hold CONTROL_IN line low on initial start up
    Prevents speaker lock out, fixes #1
    [AudioSense.cpp]
2022-04-21 Add board file to releases
2026-09-15 Add easily viewed schematic files

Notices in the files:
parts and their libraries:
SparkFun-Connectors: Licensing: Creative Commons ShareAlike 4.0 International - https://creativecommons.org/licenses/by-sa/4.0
